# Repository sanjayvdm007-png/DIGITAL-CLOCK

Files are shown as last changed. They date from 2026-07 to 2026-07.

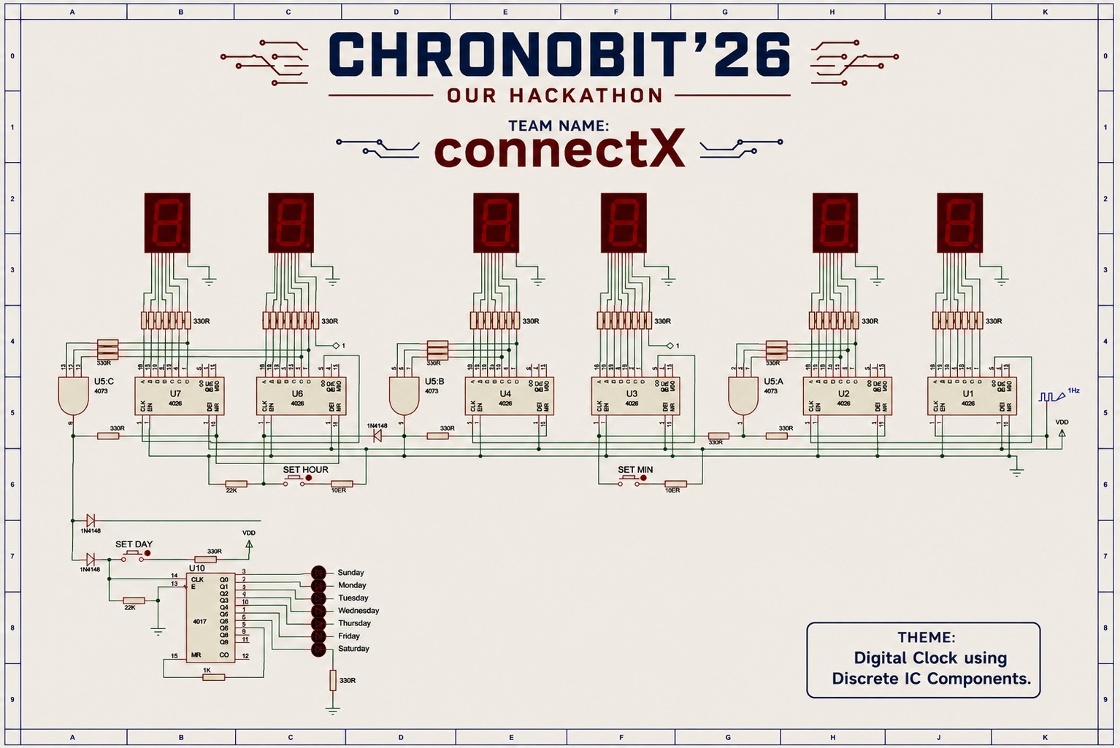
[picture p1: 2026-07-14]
Schematic.jpeg

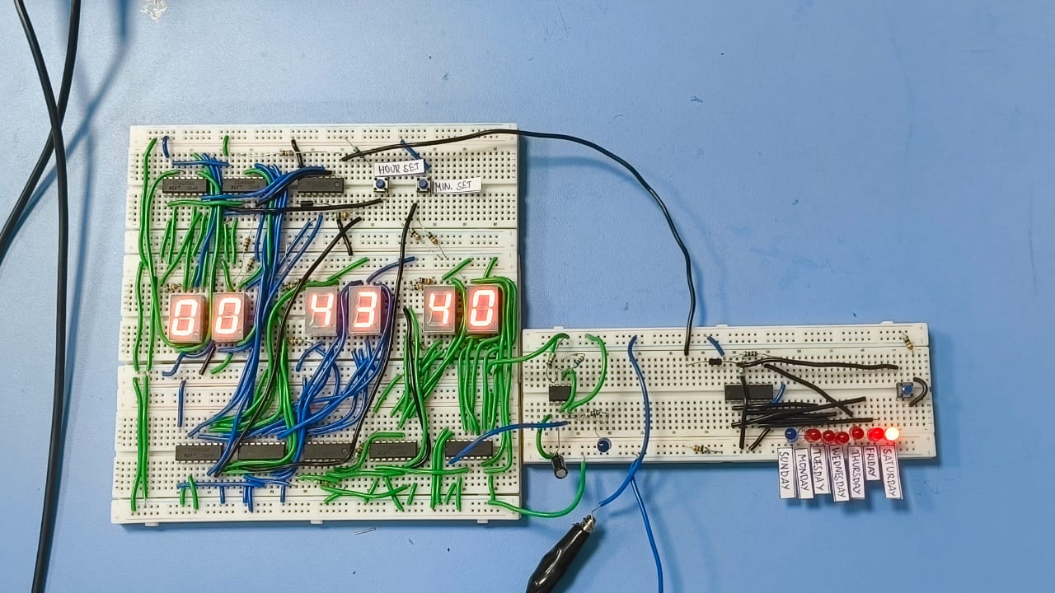
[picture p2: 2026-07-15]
Cirucit Image-2.jpeg

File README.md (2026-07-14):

<p align="center">
  ConnectX Team Logo
</p>

<h1 align="center">ChronoBit'26 — Digital Clock Using Discrete IC Components</h1>
<p align="center"><b>Team ConnectX</b> · Hackathon Project</p>

---

## ● Overview

**ChronoBit'26** is a fully discrete-logic digital clock — built entirely without a microcontroller. It displays **hours, minutes, seconds (24-hour format)** and the **day of the week**, using only CMOS counter ICs, logic gates, and 7-segment displays. Time and day can be adjusted manually using push-button inputs.

---

## ● Schematic

<p align="center">
  <a href="https://github.com/user-attachments/assets/acaa6be3-1dfc-46fe-9320-0fd341487de7">
    Full Circuit Schematic
  </a>
</p>

*Full circuit schematic showing all six CD4026 counter-driver ICs, CD4073 reset logic gates, the CD4017 day-of-week counter, and manual set switches. Click the image to view it at full resolution.*

---

## ● Block Diagram

**Signal Flow Sequence**

1 Hz Clock (555 Astable) → Seconds (00–59) → Minutes (00–59) → Hours (00–23) → Day of Week → Display Bank

---

## ● Breadboard Photo

<p align="center">
  Breadboard Build
</p>

*Physical prototype build on breadboard.*

---

## ● Demo Video

https://github.com/user-attachments/assets/d7343a4d-6b2f-4a7e-a50f-90fa1d0c52d8

---

## ● Theory of Operation

### 1. Clock Source
A **555 Timer IC configured as an astable multivibrator** generates the continuous 1 Hz square wave that acts as the master time base for the clock. The 555's charge/discharge cycle through external resistors and a capacitor sets the oscillation frequency, producing a stable square-wave output at the CLK pin. Each rising edge of this signal increments the seconds counter by one, forming the heartbeat for the entire clock chain.

### 2. Seconds, Minutes, and Hours Modules
Each time unit (Seconds, Minutes, Hours) is built from a pair of **CD4026 decade counters with integrated 7-segment decoder/drivers**:

- **Units counter (0–9):** counts up on every input pulse and drives one 7-segment digit directly.
- **Tens counter:** clocked by the *Carry Out* of the units counter, incrementing once per full units rollover.

This mirrors a standard BCD ripple-counting scheme, but the CD4026 conveniently combines the counter and 7-segment driver in a single package, eliminating the need for a separate BCD-to-7-segment decoder like the 7447.

- **Seconds Module:** counts 00–59
- **Minutes Module:** counts 00–59, clocked by Seconds' overflow (Carry Out)
- **Hours Module:** counts 00–23, clocked by Minutes' overflow (Carry Out)

### 3. Reset Logic — CD4073 Triple 3-Input AND Gates (U5:A / U5:B / U5:C)
Since the CD4026 is a natural decade (0–9) counter, each stage needs external logic to force a reset at the correct rollover point instead of counting to 15:

- **U5:A** monitors the Seconds counters and asserts **S_RST** when the count reaches 60, resetting both seconds ICs to 00.
- **U5:B** monitors the Minutes counters and asserts **M_RST** at count = 60, also generating the **carry pulse into the Hours module**.
- **U5:C** monitors the Hours counters and asserts **H_RST** at count = 24, rolling Hours back to 00 and simultaneously issuing a **midnight pulse** that auto-advances the Day-of-Week module.

Each AND gate effectively decodes a specific binary state on the counter outputs (e.g., "tens=6 AND units=0" for the 60 condition) and feeds that decoded pulse back to the **Master Reset (MR)** pins of the relevant CD4026 pair.

### 4. Day-of-Week Module — CD4017 (U10)
The **CD4017 decade counter** cycles through 7 of its 10 outputs (Q0–Q6), each output driving one LED labeled Sunday through Saturday. Only one output is HIGH at any time (one-hot encoding), making LED wiring and identification simple.

The CD4017 is clocked in two ways, combined through an **OR function**:
- **Automatically**, once per day, by the midnight rollover pulse (H_RST) from the Hours reset logic.
- **Manually**, via the SET DAY push button, for quick day correction.

### 5. Manual Time-Set Inputs
Three push buttons — **SET HOUR**, **SET MIN**, and **SET DAY** — allow direct user correction of the clock:
- Each button pulses the clock input of its respective counter stage, incrementing it by one press, independent of the automatic count chain.
- **1N4148 diodes** are used to **OR-gate** the manual pulse with the automatic carry/rollover pulse, so both sources can drive the same clock line without conflict or backfeeding into each other.

### 6. Display Bank
The clock drives **six common-cathode 7-segment displays** (HH:MM:SS), each segment current-limited by **330Ω resistors**, plus **7 LEDs** for the day-of-week indicator — for a total of 13 discrete visual outputs, all directly driven by CMOS logic with no microcontroller or display driver IC involved.

### Summary Signal Flow
```
555 Astable (1 Hz) → Seconds (00–59) → Minutes (00–59) → Hours (00–23) → Day of Week
                            │                  │                │
                      Reset @ 60         Reset @ 60        Reset @ 24 (+ midnight pulse → Day module)
```

---

## ● Components Used

| Component | Function |
|---|---|
| 555 Timer (Astable) | 1 Hz clock pulse (square wave) generation |
| CD4026 (×6) | Decade counter + 7-segment driver (Seconds, Minutes, Hours) |
| CD4073 (U5: triple 3-input AND) | Rollover detection / reset logic |
| CD4017 (U10) | Day-of-week decade counter |
| 1N4148 diodes | Diode-OR gating of manual/auto pulses |
| 7-Segment Displays (×6) | HH:MM:SS time display |
| LEDs (×7) | Day-of-week indicators |
| 330Ω / 22K / 10K / 1K resistors | Current limiting & pull-up/down |
| Push buttons (×3) | SET HOUR / SET MIN / SET DAY |

---

## ● Features

- 24-hour digital clock with day-of-week display
- 1 Hz clock pulse generated by a 555 timer astable multivibrator
- Built entirely from discrete CD4026 counters (×6) and CD4017
- Automatic reset via CD4073 AND-gate decode logic
- Manual time correction: SET HOUR, SET MIN, SET DAY
- Diode-OR gated automatic + manual day advance
- Drives 6 common-cathode 7-segment displays + 7 LED day indicators

---

## ● Team ConnectX

Built for **CHRONOBIT'26** hackathon.

**Team Members**
1. Sanjay Senthil Kumar
2. Kishore R B
3. Deshni A

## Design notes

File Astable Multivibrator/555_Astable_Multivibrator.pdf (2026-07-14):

ChronoBit'26 — Team ConnectX

# 555 Timer Astable Multivibrator

Clock Pulse (Square Wave) Generator — ChronoBit'26 Team ConnectX

### Overview

The digital clock's 1 Hz timing reference is generated using a 555 Timer IC configured as an astable multivibrator. In this mode, the 555 timer free-runs continuously without any external trigger, producing a repeating square wave at its output (pin 3). This square wave is used as the clock pulse that drives the seconds counter stage of the digital clock circuit.

### Components Used

Component | Value / Type | Function
555 Timer IC | NE555 | Generates the astable square-wave output
Resistor R1 | 68 kΩ | Charging resistor (sets HIGH time)
Resistor R2 | 10 kΩ | Charge/discharge resistor (sets LOW time)
Capacitor C | 10 uF | Timing capacitor
LED | Standard output LED | Visual indicator of the output pulse

### Theory of Operation

In astable mode, the 555 timer's internal comparators and flip-flop repeatedly charge and discharge the timing capacitor C through resistors R1 and R2, connected as shown below, with pins 2 (Trigger) and 6 (Threshold) tied together and connected to the capacitor.
- Charging phase (Output HIGH): The capacitor charges through R1 + R2 until its voltage reaches (2/3) VCC, at which point the internal comparator flips the output LOW and discharge begins.
- Discharging phase (Output LOW): The capacitor discharges through R2 alone (into pin 7, Discharge) until its voltage falls to (1/3) VCC, at which point the output flips back HIGH and the cycle repeats.
This continuous charge/discharge cycle produces a free-running square wave at the output pin, whose frequency and duty cycle depend only on the values of R1, R2, and C.

### Design Equations

Quantity | Formula
Time HIGH (t1) | t1 = 0.693 × (R1 + R2) × C
Time LOW (t2) | t2 = 0.693 × R2 × C
Total Period (T) | T = t1 + t2 = 0.693 × (R1 + 2R2) × C
Frequency (f) | f = 1.44 / [(R1 + 2R2) × C]

Duty Cycle | %D = [(R1 + R2) / (R1 + 2R2)] × 100

### Calculated Values (R1 = 68 kΩ, R2 = 10 kΩ, C = 10 uF)

Parameter | Calculated Value
Time HIGH (t1) | 0.693 × (68k + 10k) × 10uF ≈ 0.541 s
Time LOW (t2) | 0.693 × 10k × 10uF ≈ 0.069 s
Total Period (T) | ≈ 0.610 s
Frequency (f) | ≈ 1.64 Hz (theoretical)
Duty Cycle | ≈ 88.6% HIGH

Note: The oscilloscope-measured frequency (see waveform below) is close to 1 Hz, which is slightly lower than the ideal calculated value above. This is expected in practice due to resistor/capacitor tolerances, the electrolytic capacitor's ESR, and breadboard parasitic capacitance — all of which affect the actual RC charge/discharge timing.

### Hardware Implementation

The circuit was assembled on a breadboard using the 555 timer IC, the 68 kΩ and 10 kΩ resistors, the 10 uF timing capacitor, and an LED connected to the output pin (through a current-limiting resistor) to visually indicate the square-wave output.

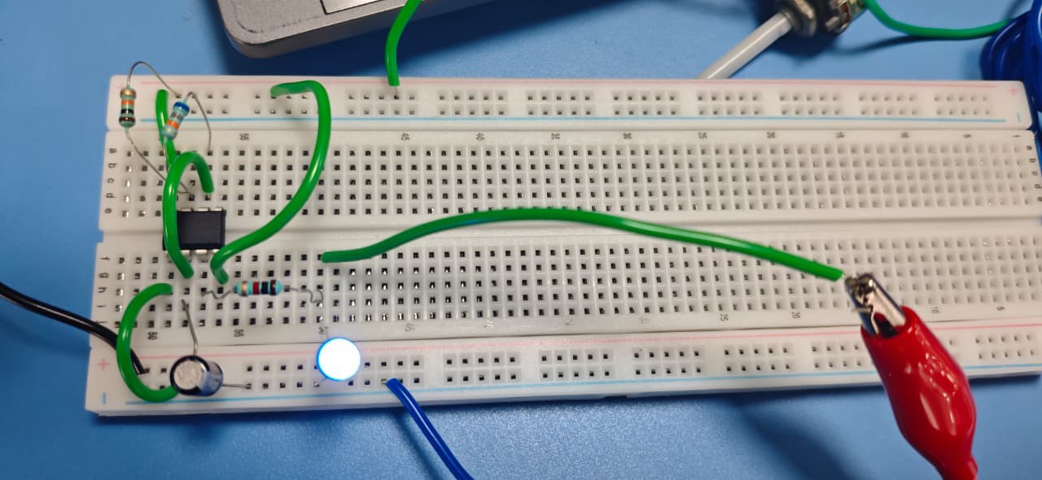
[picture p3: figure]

Fig 1: 555 Astable Multivibrator — Breadboard Prototype

### Oscilloscope Verification

The output waveform was probed and verified on a Keysight digital storage oscilloscope. The captured waveform confirms a clean, repeating square wave at the output pin, with the measured parameters shown on screen.

Measured Parameter | Oscilloscope Reading
Frequency | 974.47 mHz (≈ 0.974 Hz)
Period | 1.0262 s

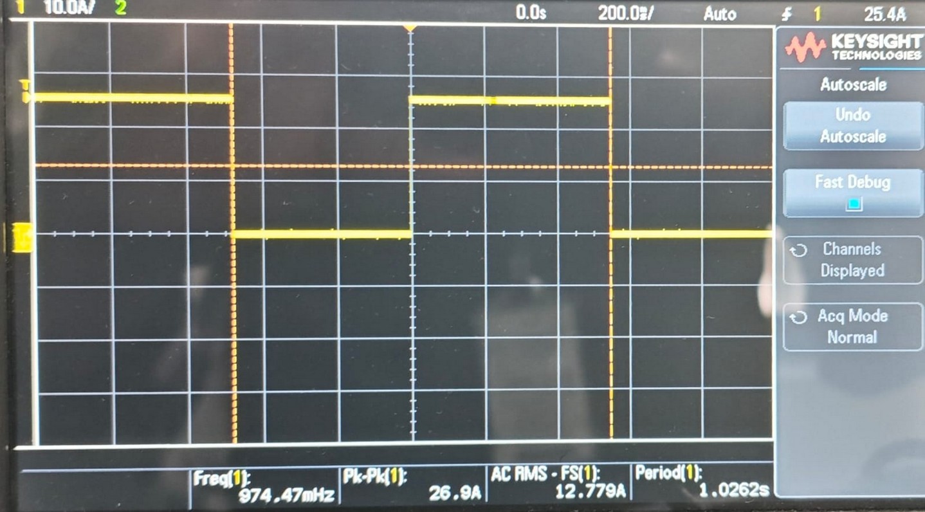
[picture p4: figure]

Fig 2: Oscilloscope Capture of the 555 Astable Output Square Wave

### Conclusion

The 555 timer astable multivibrator successfully generates a continuous square-wave clock pulse close to 1 Hz, suitable for use as the master time base of the ChronoBit'26 digital clock. This pulse is fed into the CLK input of the Seconds module, from where it propagates through the counter chain to produce the full hours-minutesseconds and day-of-week timing display.

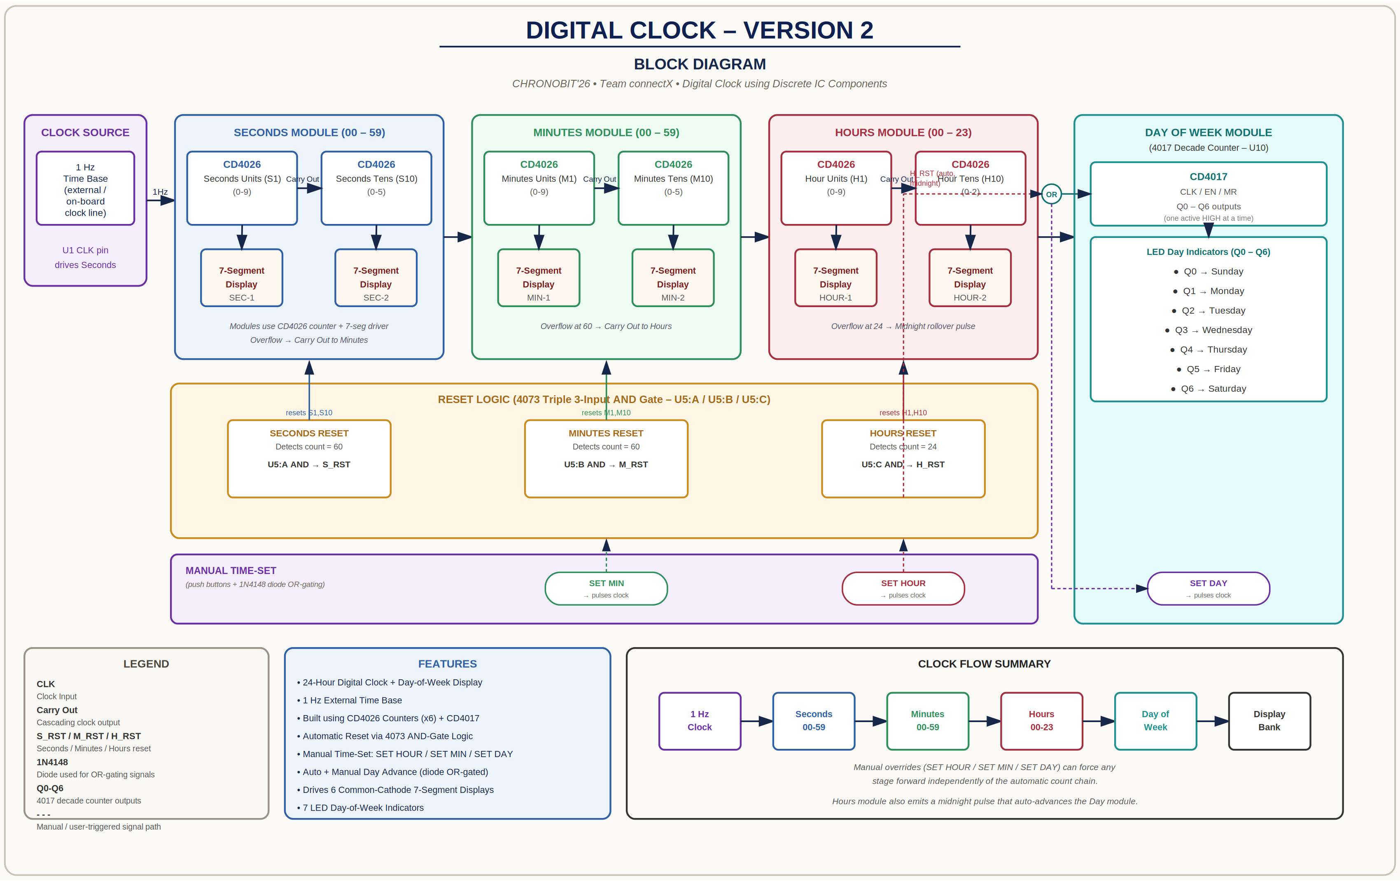
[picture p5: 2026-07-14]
Block Diagram.png

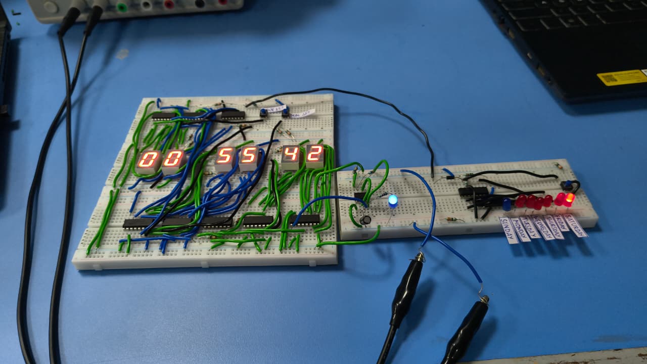
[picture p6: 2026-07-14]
Circuit Image-1.jpeg

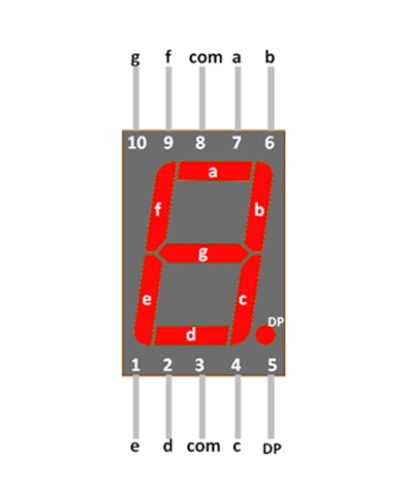
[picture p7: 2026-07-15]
Datasheet/7 Segment Pin Out.jpeg

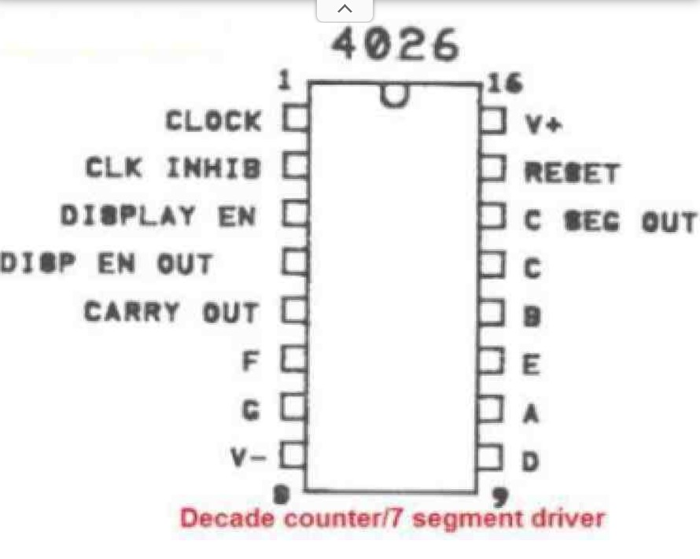
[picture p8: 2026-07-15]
Datasheet/4026 Pin Out.jpeg
